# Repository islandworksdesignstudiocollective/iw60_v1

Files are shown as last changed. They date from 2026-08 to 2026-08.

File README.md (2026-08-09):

iw60_v1

kicad_RbH6R2ADO3

****************************************************************************************

i was not impressed by the features, availability or price of other gh60 pcbs with o-ring compat so i made this

****************************************************************************************

-gh60 tray mount points

-all the baka nekos o-ring cutouts on edgecuts (afaik)

-alps+mx footprints

-onboad usb c, esd, h60 jst location yada yada

-routed to use no gnd plane cuz why not (a 2-sided fill zone has been drawn with isolation for the usb-c receptacle already, so you can choose to fill or remove it before making production files)

-duplex matrix cuz why not

-gondo reset circuit cuz why not

-bottom row is tsangan and 87u (so 7u wk/wkl or true hhkb or 87u wk with the 2 1us, as well as split space 3u) 

-does NOT support full right shift or ANSI bottom row 

-has accurately placed usb-c receptacle for gh60 standard. it is not lazily offset like most of the others i have seen, therefore i cannot confirm whether this will be well aligned with whatever pre-existing case that used a different gh60 compat pcb's 3d model to make their usb cutout

****************************************************************************************

as of right now, stm32g0b1cbt6 (and other stm mcus) seem to be in short supply, and other designers have reported issues with this mcu and qmk, so i have shelved this design. for that reason **this design has NOT been prototyped**. i don't have the energy right now to do a bom i will probably regret this in the future

the step file looks good to me. new versions of kicad are annoying to get the right thickness and export all the holes/components etc so if somethings missing its because i didn't notice :)

if you would like files for the same pcb with a different mcu you can check out iw60_v2 whenever i finish and publish that

****************************************************************************************

this is licensed under the Creative Commons Attribution Share-Alike 4.0 license, for the license's exact terms, see the LICENSE.md file

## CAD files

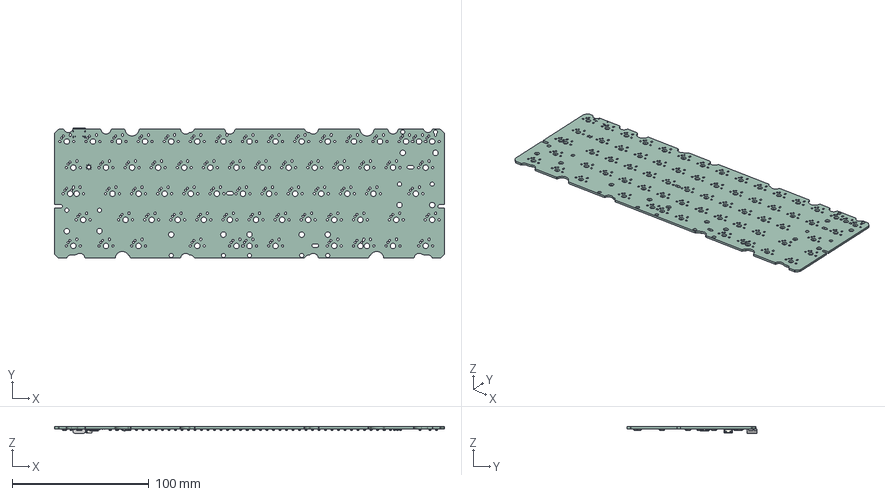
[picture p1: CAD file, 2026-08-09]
iw60.step
284.7 x 95.2 x 4.89 mm
D_SOD-123 x 65
SOT-23-3 x 3
C_0402_1005Metric x 8
R_0402_1005Metric x 9
SW_SPST_B3U-1000P
LQFP-48_7x7mm_P0.5mm
Fuse_1206_3216Metric
HRO TYPE-C-31-M-12
JST_SH_SM04B-SRSS-TB_1x04-1MP_P1.00mm_Horizontal
SOT-143
iw60_PCB

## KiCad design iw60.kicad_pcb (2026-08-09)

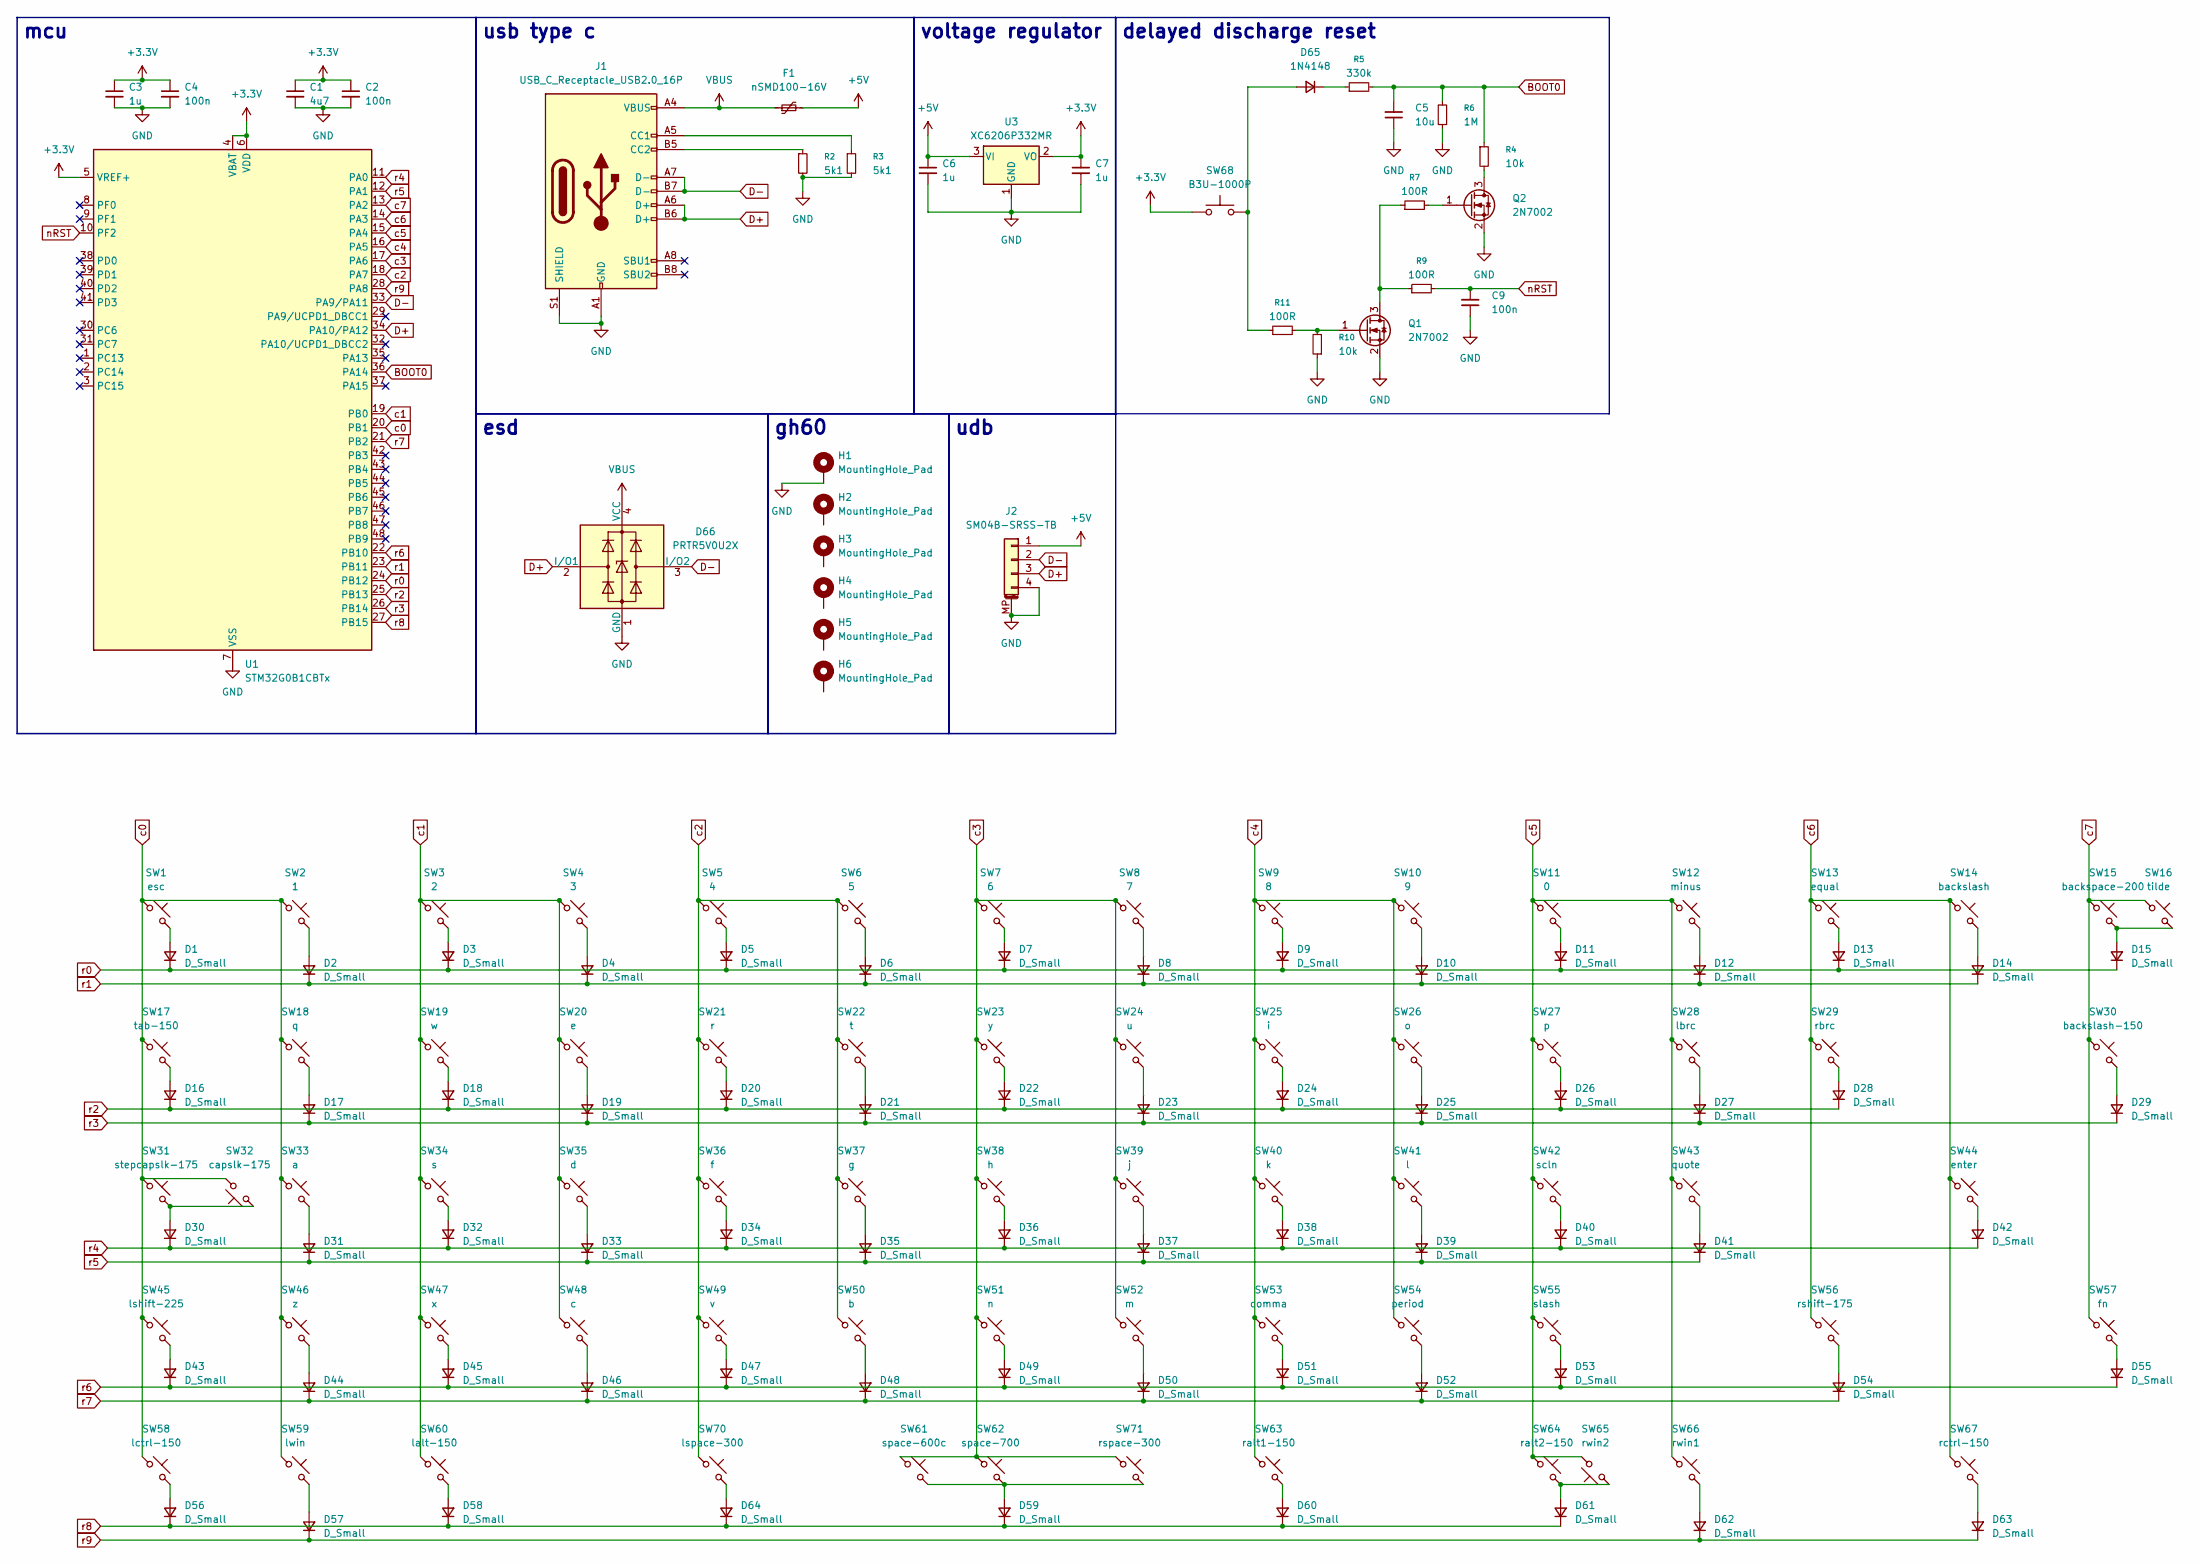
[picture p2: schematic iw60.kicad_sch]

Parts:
C1: 4u7; C_0402_1005Metric
C2, C4, C9: 100n; C_0402_1005Metric
C3, C6, C7: 1u; C_0402_1005Metric
C5: 10u; C_0402_1005Metric
D1, D2, D3, D4, D5, D6, D7, D8, D9, D10, D11, D12, D13, D14, D15, D16, D17, D18, D19, D20, D21, D22, D23, D24, D25, D26, D27, D28, D29, D30, D31, D32, D33, D34, D35, D36, D37, D38, D39, D40, D41, D42, D43, D44, D45, D46, D47, D48, D49, D50, D51, D52, D53, D54, D55, D56, D57, D58, D59, D60, D61, D62, D63, D64: D_Small; D_SOD-123
D65: 1N4148; D_SOD-123
D66: PRTR5V0U2X; SOT-143
F1: nSMD100-16V; Fuse_1206_3216Metric
H1: MountingHole_Pad; MountingHole_2.5mm_Pad_Via
H2, H3, H6: MountingHole_Pad; 5.5_5x2.5mm
H4, H5: MountingHole_Pad; 10x5_7x2.5mm
J1: USB_C_Receptacle_USB2.0_16P; USB_C_Receptacle_HRO_TYPE-C-31-M-12
J2: SM04B-SRSS-TB; JST_SH_SM04B-SRSS-TB_1x04-1MP_P1.00mm_Horizontal
Q1, Q2: 2N7002; SOT-23
R2, R3: 5k1; R_0402_1005Metric
R4, R10: 10k; R_0402_1005Metric
R5: 330k; R_0402_1005Metric
R6: 1M; R_0402_1005Metric
R7, R9, R11: 100R; R_0402_1005Metric
SW1: esc; MX-Alps-Hybrid-1U
SW2: 1; MX-Alps-Hybrid-1U-iw60-SW2
SW3: 2; MX-Alps-Hybrid-1U
SW4: 3; MX-Alps-Hybrid-1U
SW5: 4; MX-Alps-Hybrid-1U
SW6: 5; MX-Alps-Hybrid-1U
SW7: 6; MX-Alps-Hybrid-1U
SW8: 7; MX-Alps-Hybrid-1U
SW9: 8; MX-Alps-Hybrid-1U
SW10: 9; MX-Alps-Hybrid-1U
SW11: 0; MX-Alps-Hybrid-1U
SW12: minus; MX-Alps-Hybrid-1U
SW13: equal; MX-Alps-Hybrid-1U
SW14: backslash; MX-Alps-Hybrid-1U
SW15: backspace-200; MX-Alps-Hybrid-2U
SW16: tilde; MX-Alps-Hybrid-1U
SW17: tab-150; MX-Alps-Hybrid-1.5U
SW18: q; MX-Alps-Hybrid-1U
SW19: w; MX-Alps-Hybrid-1U
SW20: e; MX-Alps-Hybrid-1U
SW21: r; MX-Alps-Hybrid-1U
SW22: t; MX-Alps-Hybrid-1U
SW23: y; MX-Alps-Hybrid-1U
SW24: u; MX-Alps-Hybrid-1U
SW25: i; MX-Alps-Hybrid-1U
SW26: o; MX-Alps-Hybrid-1U
SW27: p; MX-Alps-Hybrid-1U
SW28: lbrc; MX-Alps-Hybrid-1U
SW29: rbrc; MX-Alps-Hybrid-1U
SW30: backslash-150; MX-Alps-Hybrid-1.5U
SW31: stepcapslk-175; MX-Alps-Hybrid-1.25U
SW32: capslk-175; MX-Alps-Hybrid-1.75U
SW33: a; MX-Alps-Hybrid-1U
SW34: s; MX-Alps-Hybrid-1U
SW35: d; MX-Alps-Hybrid-1U
SW36: f; MX-Alps-Hybrid-1U
SW37: g; MX-Alps-Hybrid-1U
SW38: h; MX-Alps-Hybrid-1U
SW39: j; MX-Alps-Hybrid-1U
SW40: k; MX-Alps-Hybrid-1U
SW41: l; MX-Alps-Hybrid-1U
SW42: scln; MX-Alps-Hybrid-1U
SW43: quote; MX-Alps-Hybrid-1U
SW44: enter; MX-Alps-Hybrid-2.25U
SW45: lshift-225; MX-Alps-Hybrid-2.25U
SW46: z; MX-Alps-Hybrid-1U
SW47: x; MX-Alps-Hybrid-1U
SW48: c; MX-Alps-Hybrid-1U
SW49: v; MX-Alps-Hybrid-1U
SW50: b; MX-Alps-Hybrid-1U
SW51: n; MX-Alps-Hybrid-1U
SW52: m; MX-Alps-Hybrid-1U
SW53: comma; MX-Alps-Hybrid-1U
SW54: period; MX-Alps-Hybrid-1U
SW55: slash; MX-Alps-Hybrid-1U
SW56: rshift-175; MX-Alps-Hybrid-1.75U
SW57: fn; MX-Alps-Hybrid-1U
SW58: lctrl-150; MX-Alps-Hybrid-1.5U
SW59: lwin; MX-Alps-Hybrid-1U
SW60: lalt-150; MX-Alps-Hybrid-1.5U
SW61: space-600c; MX-Alps-Hybrid-6U-ReversedStabilizers
SW62: space-700; MX-Alps-Hybrid-7U-ReversedStabilizers
SW63: ralt1-150; MX-Alps-Hybrid-1.5U
SW64: ralt2-150; MX-Alps-Hybrid-1.5U
SW65: rwin2; MX-Alps-Hybrid-1U
SW66: rwin1; MX-Alps-Hybrid-1U
SW67: rctrl-150; MX-Alps-Hybrid-1.5U
SW68: B3U-1000P; SW_SPST_B3U-1000P
SW70: lspace-300; MX-Alps-Hybrid-3U-ReversedStabilizers
SW71: rspace-300; MX-Alps-Hybrid-3U-ReversedStabilizers
U1: STM32G0B1CBTx; LQFP-48_7x7mm_P0.5mm
U3: XC6206P332MR; SOT-23-3

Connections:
+3.3V: C1.1, C2.1, C3.1, C4.1, C7.1, SW68.1, U1.4 (VBAT), U1.5 (VREF+), U1.6 (VDD), U3.2 (VO)
+5V: C6.1, F1.2, J2.1, U3.3 (VI)
BOOT0: C5.2, R4.1, R5.2, R6.2, U1.36 (PA14)
D+: D66.2 (I/O1), J1.A6 (D+), J1.B6 (D+), J2.3, U1.34 (PA10/PA12)
D-: D66.3 (I/O2), J1.A7 (D-), J1.B7 (D-), J2.2, U1.33 (PA9/PA11)
GND: C1.2, C2.2, C3.2, C4.2, C5.1, C6.2, C7.2, C9.1, D66.1 (GND), H1.1 (1_1), J1.A1 (GND), J1.A12 (GND), J1.B1 (GND), J1.B12 (GND), J1.S1 (SHIELD), J2.4, J2.MP (MountPin), Q1.2 (S), Q2.2 (S), R2.2, R3.2, R6.1, R10.1, U1.7 (VSS), U3.1 (GND)
unnamed: D1.2 (A), SW1.2
unnamed: D2.2 (A), SW2.2
unnamed: D3.2 (A), SW3.2
unnamed: D4.2 (A), SW4.2
unnamed: D5.2 (A), SW5.2
unnamed: D6.2 (A), SW6.2
unnamed: D7.2 (A), SW7.2
unnamed: D8.2 (A), SW8.2
unnamed: D9.2 (A), SW9.2
unnamed: D10.2 (A), SW10.2
unnamed: D11.2 (A), SW11.2
unnamed: D12.2 (A), SW12.2
unnamed: D13.2 (A), SW13.2
unnamed: D14.2 (A), SW14.2
unnamed: D15.2 (A), SW15.2, SW16.2
unnamed: D16.2 (A), SW17.2
unnamed: D17.2 (A), SW18.2
unnamed: D18.2 (A), SW19.2
unnamed: D19.2 (A), SW20.2
unnamed: D20.2 (A), SW21.2
unnamed: D21.2 (A), SW22.2
unnamed: D22.2 (A), SW23.2
unnamed: D23.2 (A), SW24.2
unnamed: D24.2 (A), SW25.2
unnamed: D25.2 (A), SW26.2
unnamed: D26.2 (A), SW27.2
unnamed: D27.2 (A), SW28.2
unnamed: D28.2 (A), SW29.2
unnamed: D29.2 (A), SW30.2
unnamed: D30.2 (A), SW31.2, SW32.1
unnamed: D31.2 (A), SW33.2
unnamed: D32.2 (A), SW34.2
unnamed: D33.2 (A), SW35.2
unnamed: D34.2 (A), SW36.2
unnamed: D35.2 (A), SW37.2
unnamed: D36.2 (A), SW38.2
unnamed: D37.2 (A), SW39.2
unnamed: D38.2 (A), SW40.2
unnamed: D39.2 (A), SW41.2
unnamed: D40.2 (A), SW42.2
unnamed: D41.2 (A), SW43.2
unnamed: D42.2 (A), SW44.2
unnamed: D43.2 (A), SW45.2
unnamed: D44.2 (A), SW46.2
unnamed: D45.2 (A), SW47.2
unnamed: D46.2 (A), SW48.2
unnamed: D47.2 (A), SW49.2
unnamed: D48.2 (A), SW50.2
unnamed: D49.2 (A), SW51.2
unnamed: D50.2 (A), SW52.2
unnamed: D51.2 (A), SW53.2
unnamed: D52.2 (A), SW54.2
unnamed: D53.2 (A), SW55.2
unnamed: D54.2 (A), SW56.2
unnamed: D55.2 (A), SW57.2
unnamed: D56.2 (A), SW58.2
unnamed: D57.2 (A), SW59.2
unnamed: D58.2 (A), SW60.2
unnamed: D59.2 (A), SW61.2, SW62.2, SW71.2
unnamed: D60.2 (A), SW63.2
unnamed: D61.2 (A), SW64.2, SW65.1
unnamed: D62.2 (A), SW66.2
unnamed: D63.2 (A), SW67.2
unnamed: D64.2 (A), SW70.2
unnamed: D65.2 (A), R11.1, SW68.2
unnamed: D65.1 (K), R5.1
unnamed: J1.A5 (CC1), R3.1
unnamed: J1.B5 (CC2), R2.1
unnamed: Q1.3 (D), R7.1, R9.1
unnamed: Q1.1 (G), R10.2, R11.2
unnamed: Q2.3 (D), R4.2
unnamed: Q2.1 (G), R7.2
VBUS: D66.4 (VCC), F1.1, J1.A4 (VBUS), J1.A9 (VBUS), J1.B4 (VBUS), J1.B9 (VBUS)
c0: SW1.1, SW2.1, SW17.1, SW18.1, SW31.1, SW32.2, SW33.1, SW45.1, SW46.1, SW58.1, SW59.1, U1.20 (PB1)
c1: SW3.1, SW4.1, SW19.1, SW20.1, SW34.1, SW35.1, SW47.1, SW48.1, SW60.1, U1.19 (PB0)
c2: SW5.1, SW6.1, SW21.1, SW22.1, SW36.1, SW37.1, SW49.1, SW50.1, SW70.1, U1.18 (PA7)
c3: SW7.1, SW8.1, SW23.1, SW24.1, SW38.1, SW39.1, SW51.1, SW52.1, SW61.1, SW62.1, SW71.1, U1.17 (PA6)
c4: SW9.1, SW10.1, SW25.1, SW26.1, SW40.1, SW41.1, SW53.1, SW54.1, SW63.1, U1.16 (PA5)
c5: SW11.1, SW12.1, SW27.1, SW28.1, SW42.1, SW43.1, SW55.1, SW64.1, SW65.2, SW66.1, U1.15 (PA4)
c6: SW13.1, SW14.1, SW29.1, SW44.1, SW56.1, SW67.1, U1.14 (PA3)
c7: SW15.1, SW16.1, SW30.1, SW57.1, U1.13 (PA2)
nRST: C9.2, R9.2, U1.10 (PF2)
r0: D1.1 (K), D3.1 (K), D5.1 (K), D7.1 (K), D9.1 (K), D11.1 (K), D13.1 (K), D15.1 (K), U1.24 (PB12)
r1: D2.1 (K), D4.1 (K), D6.1 (K), D8.1 (K), D10.1 (K), D12.1 (K), D14.1 (K), U1.23 (PB11)
r2: D16.1 (K), D18.1 (K), D20.1 (K), D22.1 (K), D24.1 (K), D26.1 (K), D28.1 (K), U1.25 (PB13)
r3: D17.1 (K), D19.1 (K), D21.1 (K), D23.1 (K), D25.1 (K), D27.1 (K), D29.1 (K), U1.26 (PB14)
r4: D30.1 (K), D32.1 (K), D34.1 (K), D36.1 (K), D38.1 (K), D40.1 (K), D42.1 (K), U1.11 (PA0)
r5: D31.1 (K), D33.1 (K), D35.1 (K), D37.1 (K), D39.1 (K), D41.1 (K), U1.12 (PA1)
r6: D43.1 (K), D45.1 (K), D47.1 (K), D49.1 (K), D51.1 (K), D53.1 (K), D55.1 (K), U1.22 (PB10)
r7: D44.1 (K), D46.1 (K), D48.1 (K), D50.1 (K), D52.1 (K), D54.1 (K), U1.21 (PB2)
r8: D56.1 (K), D58.1 (K), D59.1 (K), D60.1 (K), D61.1 (K), D64.1 (K), U1.27 (PB15)
r9: D57.1 (K), D62.1 (K), D63.1 (K), U1.28 (PA8)

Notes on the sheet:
esd
mcu
delayed discharge reset
usb type c
voltage regulator
gh60
udb

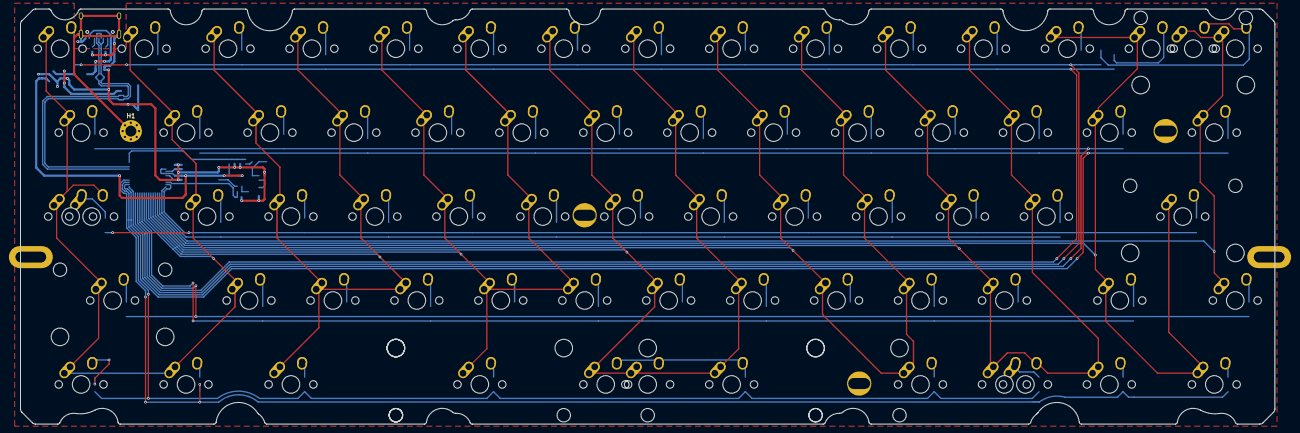
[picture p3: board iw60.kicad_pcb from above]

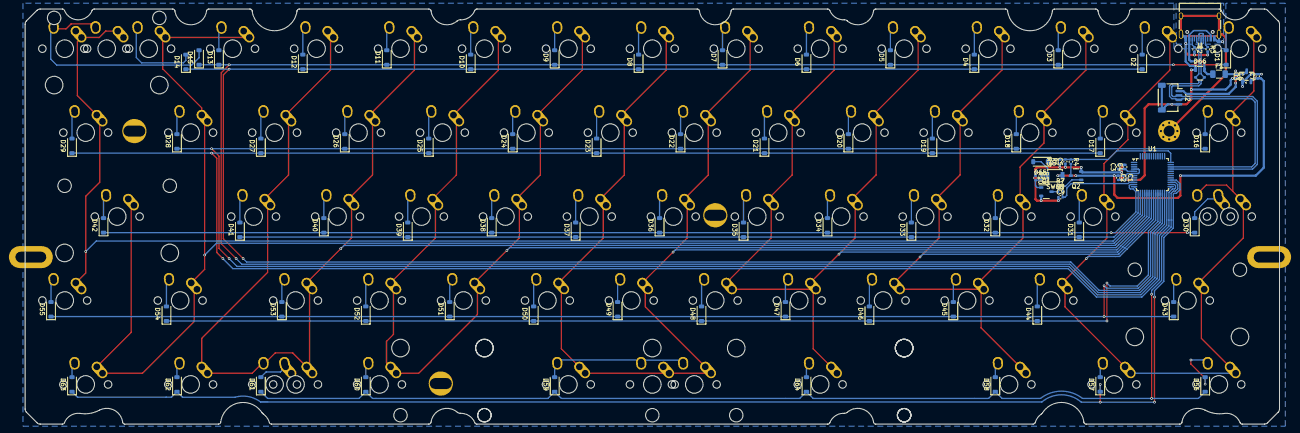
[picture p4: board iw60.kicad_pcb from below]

Board: 2 copper layers, 284.7 x 94.2 mm, 166 parts (91 on the bottom side), 98 nets.
